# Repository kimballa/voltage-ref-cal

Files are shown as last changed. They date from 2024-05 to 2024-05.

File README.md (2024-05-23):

Voltage reference calibration tool
==================================

Precision referenced voltages in 1.000V increments for calibration
of exponential converters in VCOs, VCFs, etc. 

Also usable as a manual GATE/TRIGGER signal generator.

View drawings online:
* [Schematic](https://github.com/kimballa/voltage-ref-cal/blob/main/schematic-rev1.pdf)
* [PCB](https://kicanvas.org/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)

Operation
---------

The rotary switch selects the "baseline voltage" for the output (mono jack J3 and dupont
pins J4), and can set the baseline to between 0 and 5V in 1V increments. 

When pressed, the buttons add further voltages to this; setting the baseline to 4V and
pressing the 2V button will cause the output to jump to 6V. Pressing multiple buttons
at once will sum them up; pressing the 2V and 1V buttons will add 3V to the baseline
as sent to the output, etc. 

The **REF IN** input (J1) takes a voltage input and buffers it; this voltage will be
added to the output when the +IN button is pressed. This reference input voltage can be
any voltage between the power rails, including negative voltages down to -12V.

This device is powered by +/-12VDC input via the Molex MicroFit 3.0 connector J2.  Setting
the power rails at up to +/-18V is acceptable; above this voltage level, the Zener diodes
will exceed power dissipation ratings.  The opamp will also tolerate this level just fine.

Calibration
-----------

Before use, adjust trimpots RV1 and RV2 as follows:

* Set baseline to 5V.
* Give circuit ~60 seconds to warm up.
* Measure output voltage with a DMM.
* Adjust RV1 until output (or test point TP4) reads 5.000V.
* Set baseline to 0V.
* While holding down the +5V button, adjust RV2 until output voltage reads 5.000V.
  (Or measure with DMM at test point TP5 without needing to press the +5V button.) 

Usage tips
----------

### VCO calibration

The primary purpose of the device is to assist in calibration of exponential converters
for VCOs, VCFs, or similar audio equipment. Calibration of this equipment is typically to
establish a 1V / Octave frequency response. Use the knob to set the baseline voltage
at the root of a given octave, and press the +1V button to change the output to the next
octave up in a step-function fashion. This output voltage should be fed as the CV to
the VCO.

An oscilloscope connected to the output of the VCO will show the output waveform. If the
1V/Oct response is maintained, pressing the +1V button will double the frequency and (half
of) the zeroes of the double-frequency waveform will be in the exact same position as the
zeroes of the root-frequency waveform.

Increasing the baseline voltage with the knob allows you to test this 1V / 1 octave step
response throughout the range of the DUT. To test beyond the 6th octave, set the baseline
voltage to 4V and hold down the +2V button to set the baseline at 6V, then press the +1V
button to test the 7V response, etc.

### As standalone GATE / Trigger

To test other functionality of a device that requires a GATE or trigger input, set
the baseline to 0V and press the +5V button to send a GATE signal to the DUT. The +3V
button can be used to trigger devices with a 3.3V logic input. 

Misc
----

Output can be taken from the mono jack or from the pins on connector J4. Both pins of
J4 are the same, and allow easy connection via jumper to breadboard, etc., or connection
of hook-style oscilloscope or DMM probes directly to this board. Matching ground
connection pins are available on J5. 

The output sum will top out at approximately +11.75V (possibly as low as +11V if the
output is used to drive a 2kΩ load). 

If no input is provided to the REF IN jack, it is normaled to ground (+IN button will add
0V to the output).

The rotary switch is a 1-pole, 6-position switch, Alpha MPN `SR1712F-0106-20F0A-N9-N-027`.
This device is now marked obsolete by its mfr; I built with this device because I have
several still on hand. Any 1-deck, 1-pole, 6-position BBM switch with 30 degree position
intervals will do, and there is ample space on the board to fit a different switch
footprint with minimal rerouting of traces. Alpha produces other SR1712F rotary switches
like the 8-position `SR1712F-0108` which can also be dropped in directly. (As-is, the 7th
& 8th positions will cause the baseline voltage to float and the output will be undefined
when the switch is in either of these positions; you could cause the output to be defined
by simply connecting those two pins of the switch to ground.)

License
-------
The voltage reference calibration tool © 2024 by Aaron Kimball is licensed under CC BY-SA
4.0. To view a copy of this license, visit https://creativecommons.org/licenses/by-sa/4.0/

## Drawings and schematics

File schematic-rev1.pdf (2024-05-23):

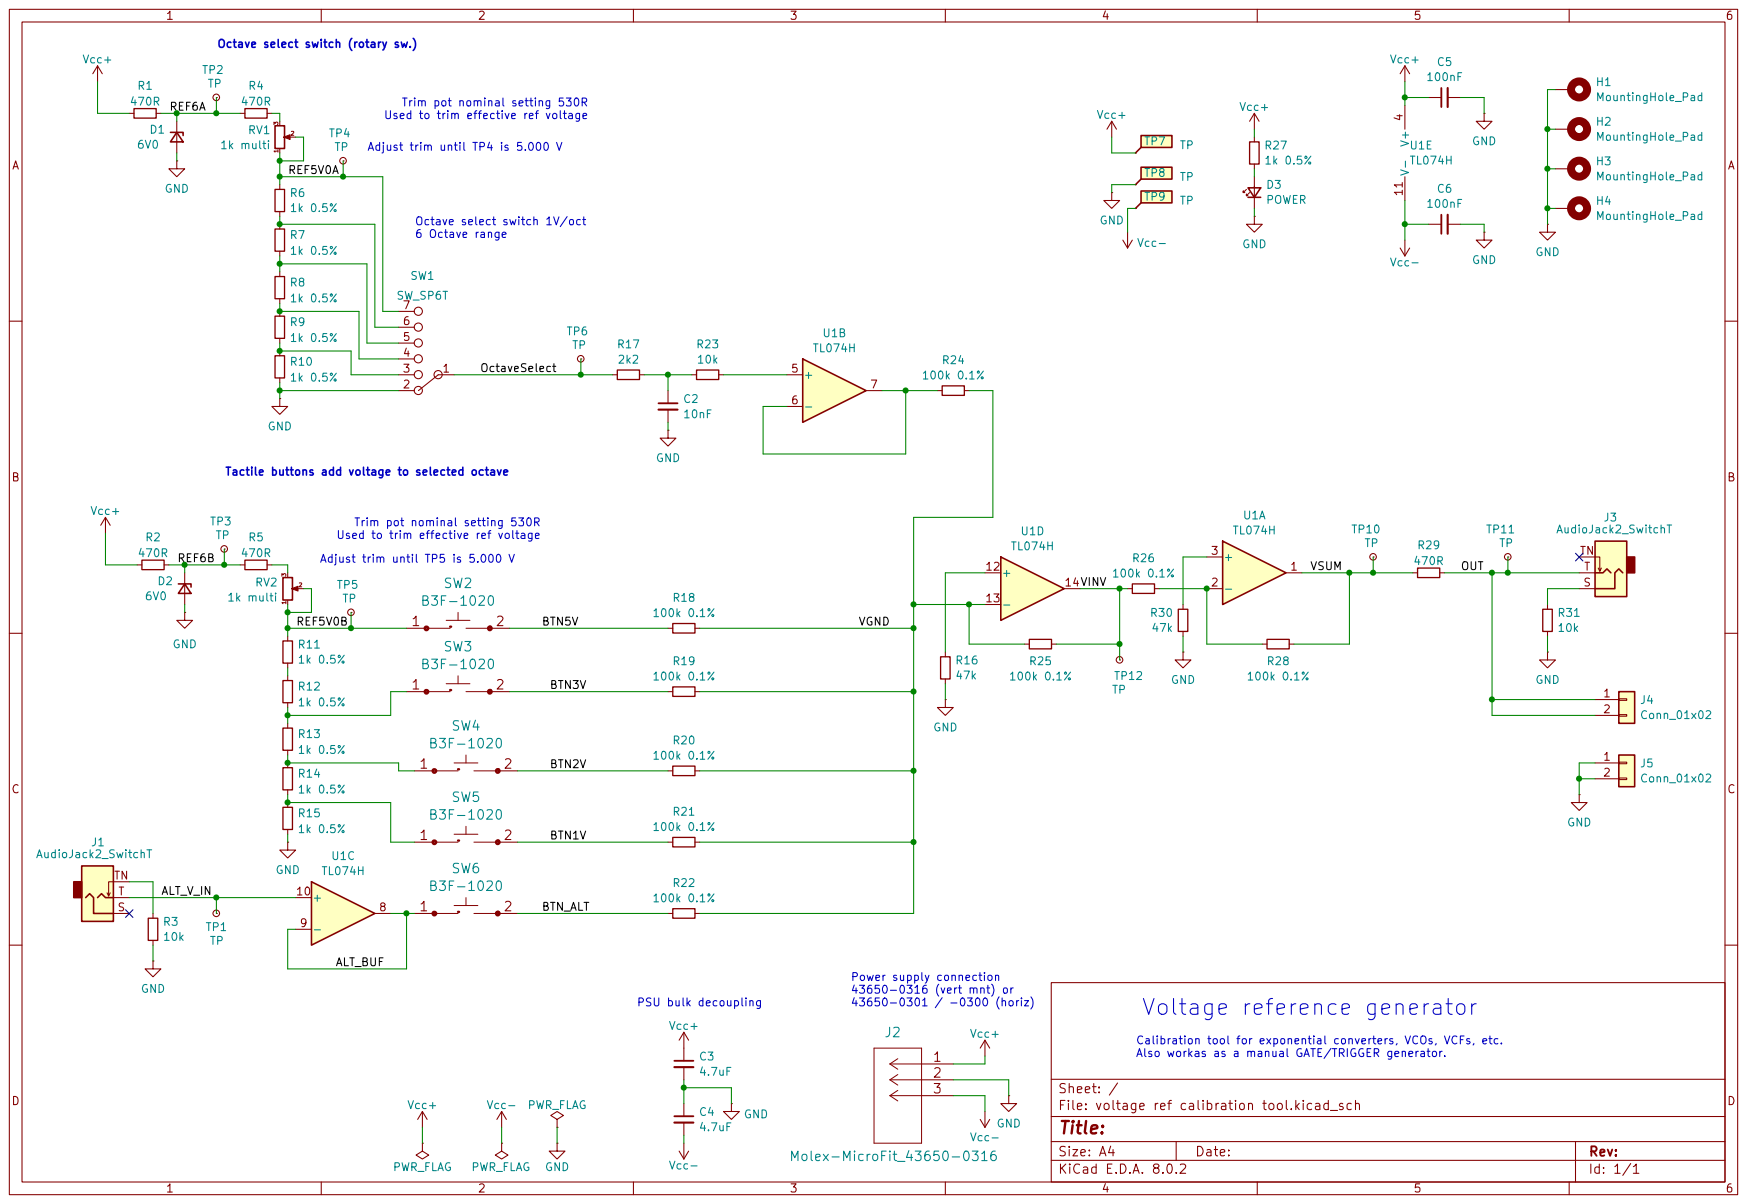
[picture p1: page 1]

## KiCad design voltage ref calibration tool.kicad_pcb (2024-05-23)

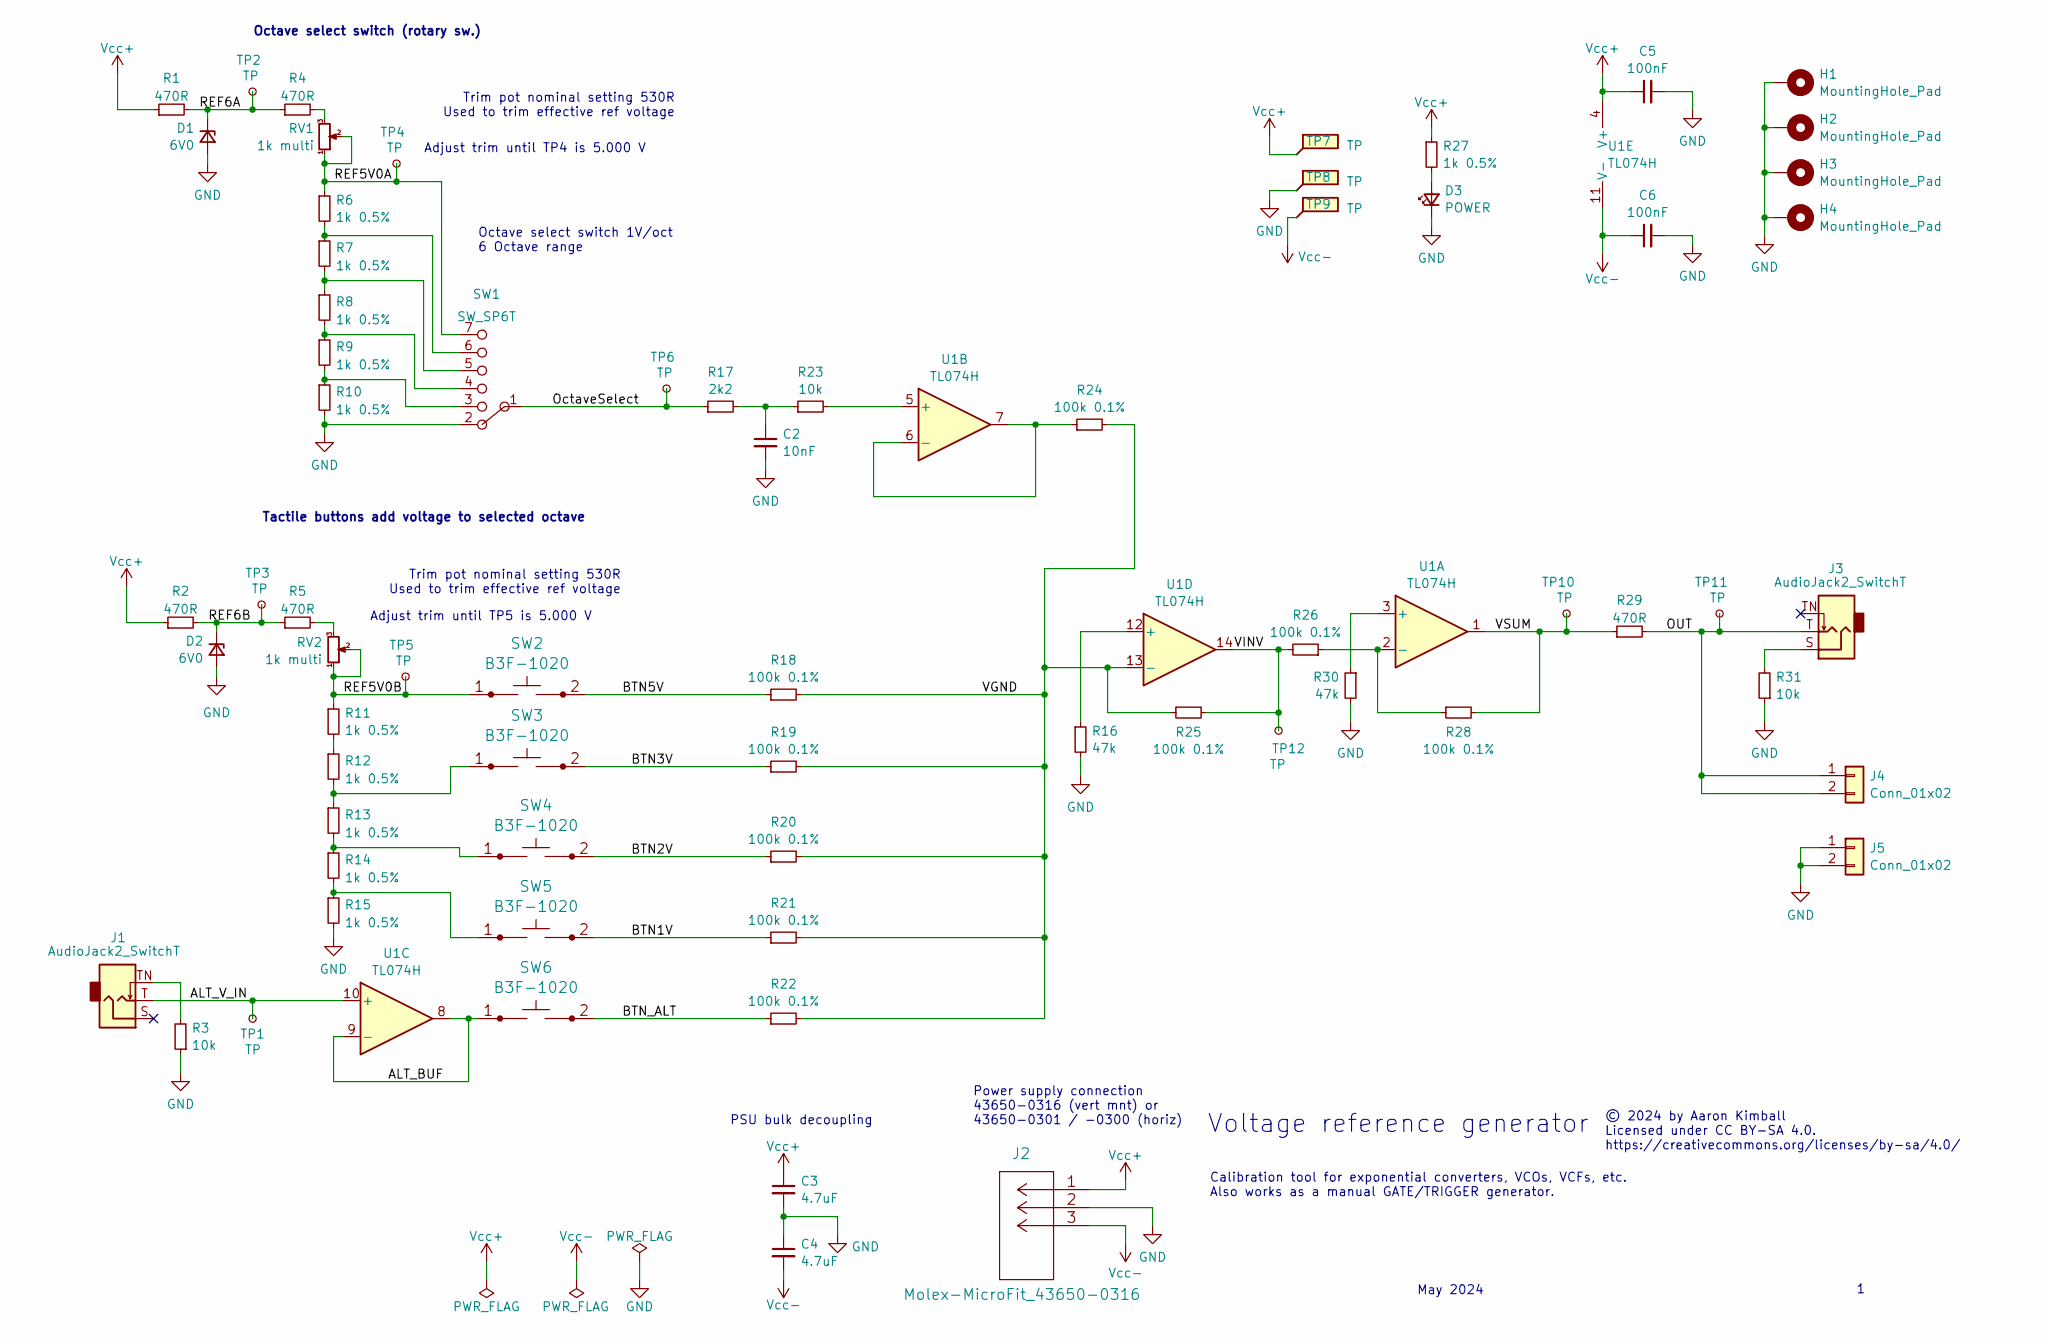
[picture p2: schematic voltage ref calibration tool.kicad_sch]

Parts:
C2: 10nF; C_0805_2012Metric_Pad1.18x1.45mm_HandSolder; MPN GRM2165C2A103JA01D
C3, C4: 4.7uF; C_1206_3216Metric_Pad1.33x1.80mm_HandSolder; MPN CL31B475KBHNFNE
C5, C6: 100nF; C_0805_2012Metric_Pad1.18x1.45mm_HandSolder; MPN CL21B104KBFNNNE
D1, D2: 6V0; D_SOD-123_SilkFix; MPN MMSZ5233C-E3-18
D3: POWER; LED_D3.0mm; MPN WP3A8ID
H1, H2, H3, H4: MountingHole_Pad; MountingHole_3.3mm_M3_Full_Standoff_Size
J1, J3: AudioJack2_SwitchT; Schurter-4832.2211; MPN 4832.2211
J2: Molex-MicroFit_43650-0316; Molex-Microfit-43650-0316; MPN 436500316
J4, J5: Conn_01x02; PinHeader_1x02_P2.54mm_Vertical; MPN 5-146850-1
R1, R2, R4, R5, R29: 470R; R_1206_3216Metric_Pad1.30x1.75mm_HandSolder; MPN RC1206FR-7W470RL
R3, R23, R31: 10k; R_0805_2012Metric_Pad1.20x1.40mm_HandSolder; MPN RMCF0805FT10K0
R6, R7, R8, R9, R10, R11, R12, R13, R14, R15, R27: 1k 0.5%; R_1206_3216Metric_Pad1.30x1.75mm_HandSolder; MPN RT1206DRE071KL
R16, R30: 47k; R_0805_2012Metric_Pad1.20x1.40mm_HandSolder; MPN RC0805FR-0747KL
R17: 2k2; R_0805_2012Metric_Pad1.20x1.40mm_HandSolder; MPN CRG0805F2K2
R18, R19, R20, R21, R22, R24, R25, R26, R28: 100k 0.1%; R_0805_2012Metric_Pad1.20x1.40mm_HandSolder; MPN ERA-6AEB104V
RV1, RV2: 1k multi; Pot_Bourns_3214W_SMD_Vert; MPN 3214W-1-102E
SW1: SW_SP6T; Alpha_SR1712F; MPN SR1712F-0106-20F0A-N9-N-027
SW2, SW3, SW4, SW5, SW6: B3F-1020; MPN B3F-1020
TP1, TP2, TP3, TP4, TP5, TP6, TP7, TP8, TP9, TP10, TP11, TP12: TP; TP_HeaderPin_P2.54mm_round
U1: TL074H; TI_SOIC_D_R-PDSO-G14_Wider_Silk; MPN TL074HIDR

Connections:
/ALT_BUF: SW6.1, U1.8, U1.9 (-)
/ALT_V_IN: J1.T, TP1.1, U1.10 (+)
/BTN1V: R21.1, SW5.2
/BTN2V: R20.1, SW4.2
/BTN3V: R19.1, SW3.2
/BTN5V: R18.1, SW2.2
/BTN_ALT: R22.1, SW6.2
/OUT: J3.T, J4.1, J4.2, R29.2, TP11.1
/OctaveSelect: R17.1, SW1.1, TP6.1
/REF5V0A: R6.1, RV1.1, RV1.2, SW1.7, TP4.1
/REF5V0B: R11.1, RV2.1, RV2.2, SW2.1, TP5.1
/REF6A: D1.1 (K), R1.2, R4.1, TP2.1
/REF6B: D2.1 (K), R2.2, R5.1, TP3.1
/VGND: R18.2, R19.2, R20.2, R21.2, R22.2, R24.2, R25.1, U1.13 (-)
/VINV: R25.2, R26.2, TP12.1, U1.14
/VSUM: R28.2, R29.1, TP10.1, U1.1
GND: C2.2, C3.2, C4.1, C5.2, C6.2, D1.2 (A), D2.2 (A), D3.1 (K), H1.1, H2.1, H3.1, H4.1, J2.2, J5.1, J5.2, R3.1, R10.2, R15.2, R16.2, R30.2, R31.1, SW1.2, TP8.1
unnamed: C2.1, R17.2, R23.1
unnamed: D3.2 (A), R27.2
unnamed: J1.TN, R3.2
unnamed: J3.S, R31.2
unnamed: R4.2, RV1.3
unnamed: R5.2, RV2.3
unnamed: R6.2, R7.1, SW1.6
unnamed: R7.2, R8.1, SW1.5
unnamed: R8.2, R9.1, SW1.4
unnamed: R9.2, R10.1, SW1.3
unnamed: R11.2, R12.1
unnamed: R12.2, R13.1, SW3.1
unnamed: R13.2, R14.1, SW4.1
unnamed: R14.2, R15.1, SW5.1
unnamed: R30.1, U1.3 (+)
unnamed: R26.1, R28.1, U1.2 (-)
unnamed: R23.2, U1.5 (+)
unnamed: R24.1, U1.6 (-), U1.7
unnamed: R16.1, U1.12 (+)
Vcc+: C3.1, C5.1, J2.1, R1.1, R2.1, R27.1, TP7.1, U1.4 (V+)
Vcc-: C4.2, C6.1, J2.3, TP9.1, U1.11 (V-)

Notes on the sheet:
May 2024
Trim pot nominal setting 530R Used to trim effective ref voltage
Adjust trim until TP4 is 5.000 V
Octave select switch (rotary sw.)
Power supply connection 43650-0316 (vert mnt) or 43650-0301 / -0300 (horiz)
PSU bulk decoupling
Octave select switch 1V/oct 6 Octave range
© 2024 by Aaron Kimball Licensed under CC BY-SA 4.0. https://creativecommons.org/licenses/by-sa/4.0/
Adjust trim until TP5 is 5.000 V
Calibration tool for exponential converters, VCOs, VCFs, etc. Also works as a manual GATE/TRIGGER generator.
Voltage reference generator
Tactile buttons add voltage to selected octave

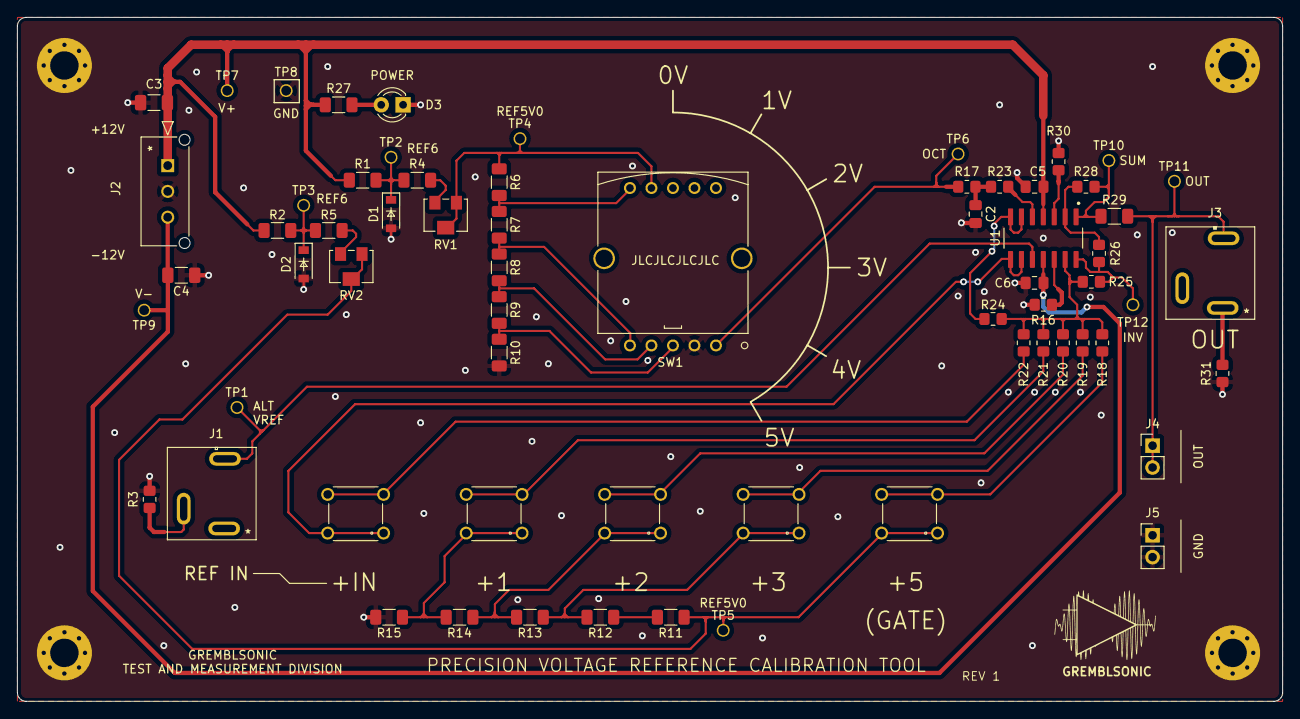
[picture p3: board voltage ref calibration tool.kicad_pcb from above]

Board: 2 copper layers, 147.1 x 79.5 mm, 69 parts (0 on the bottom side), 38 nets.

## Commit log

2024-05-12 Add empty kicad project.
    [voltage ref calibration tool.kicad_pcb, voltage ref calibration tool.kicad_sch]
2024-05-12 Draw schematic.
    [voltage ref calibration tool.kicad_sch]
2024-05-12 Reset annotations.
    [voltage ref calibration tool.kicad_sch]
2024-05-12 route board.
    [voltage ref calibration tool.kicad_pcb]
2024-05-12 improve net names.
    [voltage ref calibration tool.kicad_pcb, voltage ref calibration tool.kicad_sch]
2024-05-12 don't invert alt ref in
    [voltage ref calibration tool.kicad_pcb, voltage ref calibration tool.kicad_sch]
2024-05-13 Some final cleanup. Ready to go.
    [voltage ref calibration tool.kicad_pcb, voltage ref calibration tool.kicad_sch]
2024-05-22 Final adjust before gerber generation.
    [voltage ref calibration tool.kicad_pcb]
2024-05-22 Add RTM gerbers for rev 1.
    [voltage ref calibration tool-B_Cu.gbl, voltage ref calibration tool-B_Mask.gbs, voltage ref calibration tool-B_Paste.gbp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]
2024-05-23 Better readme.
    [voltage ref calibration tool.kicad_sch]
2024-05-23 Add rev1 RTM schematic.
2024-05-23 Add copyright legend to schematic and pcb.
    [voltage ref calibration tool.kicad_pcb, voltage ref calibration tool.kicad_sch]
